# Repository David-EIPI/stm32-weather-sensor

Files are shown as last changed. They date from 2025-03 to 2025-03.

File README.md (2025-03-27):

# stm32-weather-sensor
Outdoor air sensor using STM32WB55 and Home Assistant Zigbee integration

## Overview
The primary goal of this project is to experiment with low-power modes of the STM32 microcontroller by building a Zigbee Sleepy End Device (SED) that can operate off-grid using solar power.

## Hardware
This project is based on the [WeAct STM32WB55-Core board](https://github.com/WeActStudio/WeActStudio.STM32WB55CoreBoard "Github link: STM32WB55 Core Board").  
This compact board provides essential features:
- LDO regulator: ME6231A33M3G, with 3–18 V input and 500 mA output.
- HSE oscillator: 32 MHz.
- LSE crystal: 32.678 kHz.
- Reverse-voltage protection MOSFET.
- GPIO-controlled blue LED (PE4).
- PCB antenna.

For sensing, I've considered either the BME280 or BMP280 paired with an AHT20. Both sensors are readily available on Aliexpress, pre-soldered onto breakout boards. The difference between these sensors is minimal, but in my tests, the BMP280+AHT20 pair provided slightly more accurate temperature and humidity measurements, thus making it into the final design.

In addition to the sensors, I've selected a small outdoor solar-powered light with a replaceable battery, also from Aliexpress. It acts both as the power source and enclosure while still serving its primary purpose as an outdoor light. There's sufficient space inside the enclosure to house the controller board. However, the sensor itself must be placed outside the casing, as the enclosure may heat up significantly in direct sunlight.

To monitor battery charge levels, I have implemented a simple voltage divider. While straightforward to implement, its downside is a continuous, albeit minimal, background battery discharge. To mitigate this, I used two high-value resistors (1MΩ and 330KΩ), minimizing the discharge current. Testing with the ADC revealed that about 50 ms of sampling is needed to measure battery voltage accurately. For the project's purpose, this sampling time is acceptable.

## Zigbee Setup
Since this sensor is battery-powered, it must be configured as a sleepy end device. The firmware implements one endpoint and four measurement clusters:

- Temperature
- Humidity
- Pressure
- Voltage

Battery voltage is reported through AC voltage attributes, as ZHA does not currently support DC voltage measurements.

Pairing the STM32WB55 with ZHA can be somewhat challenging. STM's implementation of SED involves aggressive power-saving optimizations. Upon joining a Zigbee network, the firmware immediately switches to low-power mode with default polling intervals of 30 seconds. ZHA, however, expects the device to report its configuration, clusters, attributes, and values. Due to the default SED polling interval, ZHA often times out, resulting in an incomplete device setup in Home Assistant.

A solution that I've found effective—though not consistently—is temporarily enabling a fast-polling mode for a few minutes immediately after joining the network for the first time.

Additionally, several other ZHA-specific adjustments are configured in the ZHA quirk file. The default reporting configuration is overly conservative and infrequent. I also prefer sensor readings with greater decimal precision.

The connection information is stored in persistent storage, enabling automatic re-joining to the network upon controller restart.

The device page in Home Assistant should appear as follows:  
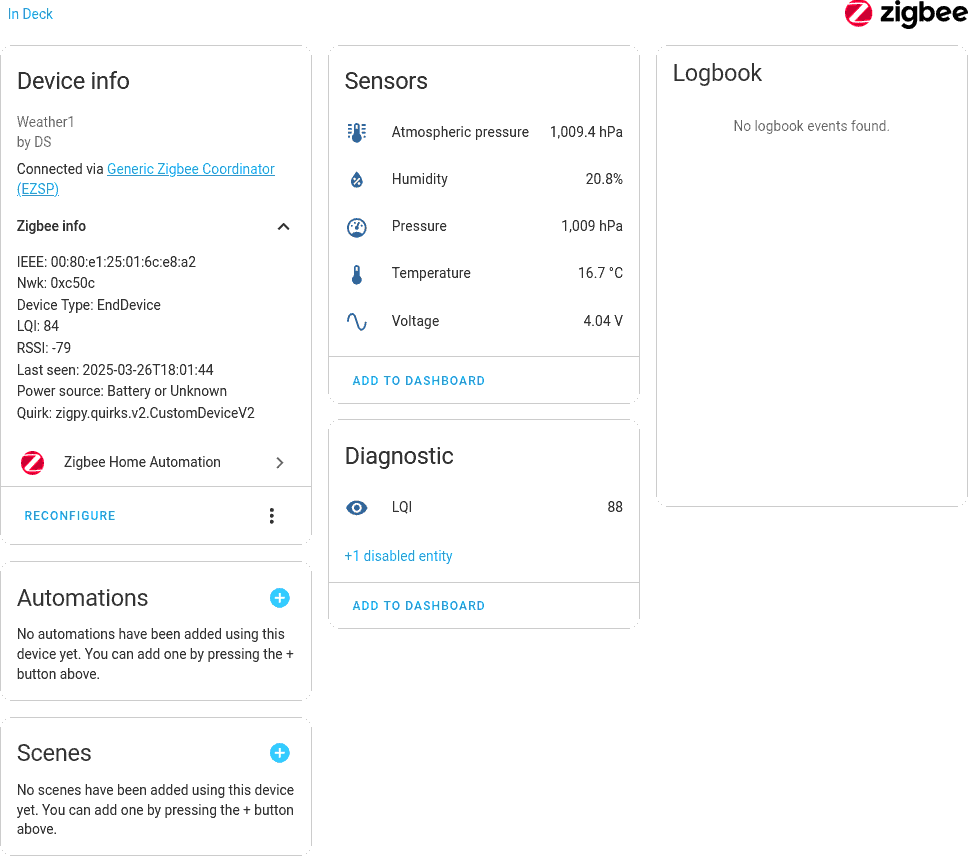
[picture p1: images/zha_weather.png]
Home Assistant device view


## Power Usage
The firmware is configured to wake up once every 20 seconds, perform sensor readings, and update the reportable attributes. The CPU spends the remainder of the time in STOP2 low-power mode. STOP2 is the deepest STOP mode and does not retain the I²C and ADC registers, requiring these peripherals to be re-initialized and shut down during each wake-up cycle.

Sensors are also powered down while the CPU is in the stopped state, thus requiring re-initialization upon wake-up.

The active phase lasts approximately 0.5 seconds and consumes about 5–15 mA for the entire system, including CPU, RF, and sensors. During the stopped phase, the CPU draws approximately 10 µA. Consequently, the average consumption is expected to be around 100–200 µA.

Without access to an integrating current meter, I resorted to a simple approach using an ultracapacitor to measure the average current consumption.

I charged a 30 F capacitor to 5.3 V and used it to power the sensor board. Voltage decay was recorded by the sensor itself, with Home Assistant capturing the data over time. After a few days, I obtained the voltage-versus-time plot shown below:  
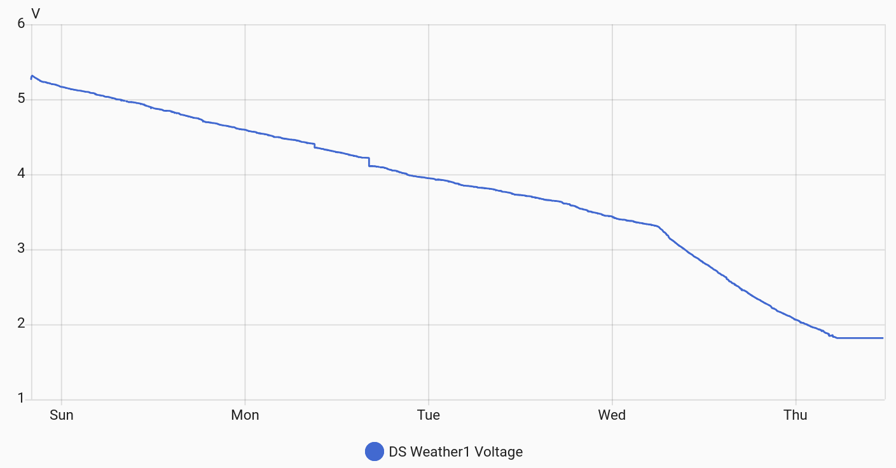
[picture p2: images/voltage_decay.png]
Capacitor voltage vs time


The voltage decay rate remains constant until reaching the LDO threshold of 3.3 V. At 1.8 V, the circuit shuts down completely. From the voltage decay slope, average current consumption can be estimated using:

I = C × dV/dt

The resulting calculation indicates approximately 200 µA of total current. Given that the ultracapacitor has a documented self-discharge rate of about 100 µA, the sensor itself consumes around 100 µA.

The documented battery capacity is 1200 mAh, thus a full day's operation of the sensor would minimally impact the battery's charge.

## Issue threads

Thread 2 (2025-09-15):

Join button

David-EIPI, 2025-09-15:
You are correct, most manufacturers add a button that initiates network discovery and joining. However, for my use case I did not expect frequent re-connections, so I have made it simple. On startup, my code attempts to join any network that is open for joining. Then my sensor will remain joined until the network coordinator requests it to leave.
It is fairly easy to implement a button if you need one. Just add a GPIO handler that sets some button press flag, and modify APP_ZIGBEE_NwkForm() to delay network formation until the button is pressed.

Closed 2025-09-22.

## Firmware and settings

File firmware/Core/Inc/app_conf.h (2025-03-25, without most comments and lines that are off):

#define APP_CONF_H
#include "hw.h"
#include "hw_conf.h"
#include "hw_if.h"
#define CFG_TL_EVT_QUEUE_LENGTH 5
#define CFG_TL_MOST_EVENT_PAYLOAD_SIZE 255
#define TL_EVENT_FRAME_SIZE ( TL_EVT_HDR_SIZE + CFG_TL_MOST_EVENT_PAYLOAD_SIZE )
#define CFG_DEBUG_TRACE_UART    hw_lpuart1
#define CFG_CONSOLE_MENU
#define CFG_CLI_UART            No UART selected
#define CFG_USB_INTERFACE_ENABLE    0
#define HAL_IPCC_TX_IRQHandler(...)  HW_IPCC_Tx_Handler( )
#define HAL_IPCC_RX_IRQHandler(...)  HW_IPCC_Rx_Handler( )
#define CFG_FULL_LOW_POWER    1
#if (CFG_FULL_LOW_POWER == 1)
#undef CFG_LPM_SUPPORTED
#define CFG_LPM_SUPPORTED   1
#endif
#define HAL_RTCEx_WakeUpTimerIRQHandler(...)  HW_TS_RTC_Wakeup_Handler( )
#define CFG_RTCCLK_DIVIDER_CONF 0
#if (CFG_RTCCLK_DIVIDER_CONF == 0)
#define CFG_RTCCLK_DIV            (16)
#define CFG_RTC_WUCKSEL_DIVIDER   (0)
#define CFG_RTC_ASYNCH_PRESCALER  (0x0F)
#define CFG_RTC_SYNCH_PRESCALER   (0x7FFF)
#else
#if (CFG_RTCCLK_DIVIDER_CONF == 2)
#define CFG_RTC_WUCKSEL_DIVIDER (3)
#endif
#if (CFG_RTCCLK_DIVIDER_CONF == 4)
#define CFG_RTC_WUCKSEL_DIVIDER (2)
#endif
#if (CFG_RTCCLK_DIVIDER_CONF == 8)
#define CFG_RTC_WUCKSEL_DIVIDER (1)
#endif
#if (CFG_RTCCLK_DIVIDER_CONF == 16)
#define CFG_RTC_WUCKSEL_DIVIDER (0)
#endif
#define CFG_RTCCLK_DIV              CFG_RTCCLK_DIVIDER_CONF
#define CFG_RTC_ASYNCH_PRESCALER    (CFG_RTCCLK_DIV - 1)
#define CFG_RTC_SYNCH_PRESCALER     (DIVR( LSE_VALUE, (CFG_RTC_ASYNCH_PRESCALER+1) ) - 1 )
#endif
#define CFG_TS_TICK_VAL           DIVR( (CFG_RTCCLK_DIV * 1000000), LSE_VALUE )
#define CFG_TS_TICK_VAL_PS        DIVR( ((uint64_t)CFG_RTCCLK_DIV * 1e12), (uint64_t)LSE_VALUE )
typedef enum
{
  CFG_TIM_PROC_ID_ISR,
  CFG_TIM_ZIGBEE_APP_BME280_REPEAT,
  CFG_TIM_ZIGBEE_STOP_FASTPOLL_ONESHOT,
} CFG_TimProcID_t;
#define CFG_HW_RESET_BY_FW         0
#define CFG_DEBUGGER_SUPPORTED    0
#if (CFG_FULL_LOW_POWER == 1)
#undef CFG_DEBUGGER_SUPPORTED
#define CFG_DEBUGGER_SUPPORTED    0
#endif
#define CFG_DEBUG_TRACE    0
#if (CFG_FULL_LOW_POWER == 1)
#undef CFG_DEBUG_TRACE
#define CFG_DEBUG_TRACE      0
#endif
#define CFG_DEBUG_TRACE_LIGHT     1
#define CFG_DEBUG_TRACE_FULL      1
#if (( CFG_DEBUG_TRACE != 0 ) && ( CFG_DEBUG_TRACE_LIGHT == 0 ) && (CFG_DEBUG_TRACE_FULL == 0))
#undef CFG_DEBUG_TRACE_FULL
#undef CFG_DEBUG_TRACE_LIGHT
#define CFG_DEBUG_TRACE_FULL      0
#define CFG_DEBUG_TRACE_LIGHT     1
#endif
#if ( CFG_DEBUG_TRACE == 0 )
#undef CFG_DEBUG_TRACE_FULL
#undef CFG_DEBUG_TRACE_LIGHT
#define CFG_DEBUG_TRACE_FULL      0
#define CFG_DEBUG_TRACE_LIGHT     0
#endif
#define DBG_TRACE_USE_CIRCULAR_QUEUE 1
#define DBG_TRACE_MSG_QUEUE_SIZE 4096
#define MAX_DBG_TRACE_MSG_SIZE   1024
#define APPLI_CONFIG_LOG_LEVEL    LOG_LEVEL_DEBG
#define APPLI_PRINT_FILE_FUNC_LINE    0
#define SENSOR_INTERVAL 20
#define USE_AHT20 1
#define MANUFACTURER_NAME "\x02" "DS"
#define MODEL_NAME "\x08" "Weather1"
#define LOCATION "\x0f" "Weather station"
#define DEFAULT_REPORT_MIN SENSOR_INTERVAL
#define DEFAULT_REPORT_MAX (DEFAULT_REPORT_MIN*60)
#define REPORT_KICK 0
#define USE_FASTPOLL 600
#define PERSIST_TIMEOUT 1000000
#define CFG_NB_OF_PAGE                          (16U)
#define CFG_EE_BANK0_SIZE                       (CFG_NB_OF_PAGE * HW_FLASH_PAGE_SIZE)
#define CFG_EE_BANK1_SIZE                       (CFG_NB_OF_PAGE * HW_FLASH_PAGE_SIZE)
#define CFG_NVM_BASE_ADDRESS                    ( 0x60000U )
#define CFG_EE_BANK0_MAX_NB                     (1000U)                  // In U32 words
#define CFG_EE_BANK1_MAX_NB                     (1000U)                  // In U32 words
#define ST_PERSIST_MAX_ALLOC_SZ                 (4U*CFG_EE_BANK0_MAX_NB) // Max data in bytes
#define ST_PERSIST_FLASH_DATA_OFFSET            (4U)
#define ZIGBEE_DB_START_ADDR                    (0U)
#define CFG_EE_AUTO_CLEAN                       (1U)
#define CFG_EE_TIMEOUT                          (10000U)                 // in milliseconds
#define CFG_USE_SMPS 1
typedef enum
{
  CFG_TASK_NOTIFY_FROM_M0_TO_M4,
  CFG_TASK_REQUEST_FROM_M0_TO_M4,
  CFG_TASK_ZIGBEE_NETWORK_FORM,
  CFG_TASK_SYSTEM_HCI_ASYNCH_EVT,
#if (CFG_USB_INTERFACE_ENABLE != 0)
  CFG_TASK_VCP_SEND_DATA,
#endif
  CFG_TASK_MAIN_LOOP,
  CFG_TASK_ZIGBEE_STOP_FASTPOLL,
  CFG_TASK_NBR
} CFG_IdleTask_Id_t;
#define EVENT_ACK_FROM_M0_EVT        (1U << CFG_EVT_ACK_FROM_M0_EVT)
#define EVENT_SYNCHRO_BYPASS_IDLE    (1U << CFG_EVT_SYNCHRO_BYPASS_IDLE)
typedef enum
{
  CFG_SCH_PRIO_0,
  CFG_SCH_PRIO_1,
  CFG_SCH_PRIO_NBR
} CFG_SCH_Prio_Id_t;
typedef enum
{
  CFG_EVT_SYSTEM_HCI_CMD_EVT_RESP,
  CFG_EVT_ACK_FROM_M0_EVT,
  CFG_EVT_SYNCHRO_BYPASS_IDLE,
  CFG_EVT_ZIGBEE_STARTUP_ENDED,
} CFG_IdleEvt_Id_t;
#define EVENT_ACK_FROM_M0_EVT           (1U << CFG_EVT_ACK_FROM_M0_EVT)
#define EVENT_SYNCHRO_BYPASS_IDLE       (1U << CFG_EVT_SYNCHRO_BYPASS_IDLE)
#define EVENT_ZIGBEE_STARTUP_ENDED      (1U << CFG_EVT_ZIGBEE_STARTUP_ENDED)
typedef enum
{
  CFG_LPM_APP,
  CFG_LPM_SENSORS,
  CFG_LPM_FASTPOLL,
} CFG_LPM_Id_t;
#define CFG_OTP_BASE_ADDRESS    OTP_AREA_BASE
#define CFG_OTP_END_ADRESS      OTP_AREA_END_ADDR

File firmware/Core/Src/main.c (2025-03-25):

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
/* Includes ------------------------------------------------------------------*/
#include "main.h"

/* USER CODE BEGIN Includes */
#include "stm32_seq.h"
#include "stm_logging.h"
#include "dbg_trace.h"
#include "zigbee.h"
#include "app_zigbee.h"
#include "stm32_lpm.h"
#include "stm32_lpm_if.h"
#include "hw_if.h"

#include "zcl/general/zcl.press.meas.h"
#include "zcl/general/zcl.temp.meas.h"
#include "zcl/general/zcl.elec.meas.h"
#include "zcl/general/zcl.wcm.h"

#include "bme280_support.h"
#include "aht20.h"
/* USER CODE END Includes */

/* USER CODE BEGIN PD */


#define HW_TS_SERVER_20S_NB_TICKS                    (SENSOR_INTERVAL *1000*1000/CFG_TS_TICK_VAL) /* 20s */
/* USER CODE END PD */


I2C_HandleTypeDef hi2c1;

IPCC_HandleTypeDef hipcc;

IWDG_HandleTypeDef hiwdg;

UART_HandleTypeDef hlpuart1;

RTC_HandleTypeDef hrtc;

/* USER CODE BEGIN PV */
struct bme280_data bme280_meas_data;

#if USE_AHT20

static aht20_data_t aht20_data;

#endif

uint8_t hwSensorTimerId = CFG_HW_TS_MAX_NBR_CONCURRENT_TIMER;
uint8_t hwActiveTimerId = CFG_HW_TS_MAX_NBR_CONCURRENT_TIMER;

static unsigned SysTicks_us = 0;

uint8_t adc_num_conversions = 0;
int vrefplus = 0;
int internal_tc = 0;
int adc1_voltage = 0;

unsigned iwdg_update_req = 0;
unsigned iwdg_update_cnt = 0;

/* USER CODE END PV */

void SystemClock_Config(void);
void PeriphCommonClock_Config(void);
static void MX_GPIO_Init(void);
static void MX_IPCC_Init(void);
static void MX_RTC_Init(void);
static void MX_I2C1_Init(void);
static void MX_IWDG_Init(void);
static void MX_ADC1_Init(void);
static void MX_LPTIM1_Init(void);
static void MX_LPUART1_UART_Init(void);
static void MX_RF_Init(void);
/* USER CODE BEGIN PFP */
static void setup_lptimer(void);

static void ADC_check(int idx);
static void ADC_check_print(void);

/* USER CODE END PFP */

/* USER CODE BEGIN 0 */

static uint32_t dbg_counter = 0, dbg_prev = 0;

static int wait_for_flag(uint32_t (*flag_func)(const ADC_TypeDef *ADCx), uint32_t flag)
{
	uint32_t timeout = 1000; //ms
	uint32_t count = 0;
	uint32_t prev = HAL_GetTick();

	while (flag_func(ADC1) != flag)
	{
		HAL_Delay(20);
		count = HAL_GetTick() - prev;
		if (count > timeout) {
			dbg_counter = count;
			dbg_prev = prev;
			return -1;
		}
	}
	return count;
}

static void read_voltage_and_temp(void)
{
	int32_t adc_readings[adc_num_conversions];
	int32_t wait_time[adc_num_conversions];

	if (LL_ADC_IsActiveFlag_ADRDY(ADC1) == 0) { /* ADC is not ready */
		APP_DBG("ADC not ready.");
		return;
	}

	unsigned i;
	for (i = 0; i < adc_num_conversions; i++) {
		LL_ADC_REG_StartConversion(ADC1);
		wait_time[i] = wait_for_flag(LL_ADC_IsActiveFlag_EOC, 1);
		if (wait_time[i] < 0) {
			APP_DBG("ADC CH%d timeout", i);
			return;
		}
		adc_readings[i] = LL_ADC_REG_ReadConversionData12(ADC1);
	}

	int vref_adc = adc_readings[0];
	int temp_adc = adc_readings[1];
	int ch1_adc  = adc_readings[2];

	if (vref_adc > 0)
		vrefplus = __LL_ADC_CALC_VREFANALOG_VOLTAGE(vref_adc, LL_ADC_RESOLUTION_12B);
	if(temp_adc > 0)
		internal_tc = 100* __LL_ADC_CALC_TEMPERATURE(vrefplus, temp_adc, LL_ADC_RESOLUTION_12B);

	adc1_voltage = __LL_ADC_CALC_DATA_TO_VOLTAGE(vrefplus, ch1_adc, LL_ADC_RESOLUTION_12B);
}

/* Enable the ADC as explained in Examples_LL/ADC_SingleConversion_TriggerSW_Init */
static int adc_enable(void)
{
	/* First, turn on the power */
	LL_ADC_DisableDeepPowerDown(ADC1);
	LL_ADC_EnableInternalRegulator(ADC1);

	/* Delay for voltage regulator stabilization */
	HAL_Delay(1);

	/* Clear ADC group regular conversion flag and overrun flag               */
    /* (To ensure of no unknown state from potential previous ADC operations) */
	LL_ADC_ClearFlag_EOC(ADC1);
	LL_ADC_ClearFlag_EOS(ADC1);
	LL_ADC_ClearFlag_EOSMP(ADC1);
	LL_ADC_ClearFlag_OVR(ADC1);

	/* Run ADC self calibration and wait for completion */
    LL_ADC_StartCalibration(ADC1, LL_ADC_SINGLE_ENDED);
    if (wait_for_flag(LL_ADC_IsCalibrationOnGoing, 0) < 0) {
    	ADC_check(1);
    	return -1;
    }
	/* Another short delay is needed here */
	HAL_Delay(1);

	/* Now enable the ADC and wait for its Ready flag */
	LL_ADC_Enable(ADC1);
	if (wait_for_flag(LL_ADC_IsActiveFlag_ADRDY, 1) < 0) {
		return -2;
	}
//	APP_DBG("ADC regs: CR:0x%x ISR:0x%x", ADC1->CR, ADC1->ISR);
	return 0;
}

/* Disable the ADC as described in RM034*/
static void adc_disable(void)
{
	/* Stop conversions and wait for ADSTP to clear*/
	LL_ADC_REG_StopConversion(ADC1);
	while (LL_ADC_REG_IsStopConversionOngoing(ADC1)) {}

	/* Clear Ready flag */
	LL_ADC_ClearFlag_ADRDY(ADC1);

	/* Set disable bit and wait for ADEN to clear */
	LL_ADC_Disable(ADC1);
	while (LL_ADC_IsEnabled(ADC1)) {}

	/* Finally, cut the power */
	LL_ADC_DisableInternalRegulator(ADC1);
	LL_ADC_EnableDeepPowerDown(ADC1);
}


/*
 * Main application loop. Read the sensors and update Zigbee attributes.
 * */

void seq_main_loop(void)
{
	LL_GPIO_SetOutputPin(BME280_Supply_GPIO_Port, BME280_Supply_Pin);

	HAL_Delay(10);

	MX_I2C1_Init();

	int adc_res = adc_enable();
	if (0 == adc_res) {
		read_voltage_and_temp();
		if (0 == adc1_voltage) {
			APP_DBG("ADC regs: CR:0x%x ISR:0x%x", ADC1->CR, ADC1->ISR);
		}
	} else {
		APP_DBG("ADC error: %d", adc_res);
		ADC_check_print();
		APP_DBG("Timeout counters: %u, %u", dbg_counter, dbg_prev);
	}

	adc_disable();

	/*
	 * Voltage at the ADC pin is produced by the voltage divider, where R1=1M, and R2=330K.
	 * After calibration I have obtained this ratio: 8105/2048, choosing power of 2 as a scale for performance reason.
	 * */
	int vdd_divided = (adc1_voltage * 8105) / 2048;

	/* Update the ADC attributes so that C2 can possibly begin transmission while we read the I2C sensors. */
	APP_ZIGBEE_update_ADC_outputs(vdd_divided);

	int8_t bme280_status = bme280_setup();

#if USE_AHT20
	HAL_Delay(50);
	aht_status_t aht_status = aht20_setup();
#endif

	if (BME280_OK == bme280_status) {
		bme280_status = bme280_read_measurements(&bme280_meas_data);
		bme280_meas_data.humidity = (bme280_meas_data.humidity * 100 + 512) / 1024;
	}

	if (BME280_OK != bme280_status) {
		bme280_meas_data.temperature = ZCL_TEMP_MEAS_UNKNOWN;
		bme280_meas_data.pressure = ZCL_PRESS_MEAS_UNKNOWN;
		bme280_meas_data.humidity = ZCL_WC_MEAS_UNKNOWN;

	}

#if USE_AHT20
	bme280_meas_data.humidity = ZCL_WC_MEAS_UNKNOWN;
	if (AHT_NO_ERROR == aht_status) {
		HAL_Delay(50);
		aht_status = aht20_read_measurements(&aht20_data);
		if (AHT_NO_ERROR == aht_status) {
			bme280_meas_data.humidity = aht20_data.humidity;
		}

		/* Use AHT temperature measurement if BMP280 data is unavailable. */
		if (ZCL_TEMP_MEAS_UNKNOWN == bme280_meas_data.temperature) {
			bme280_meas_data.temperature = aht20_data.temperature;
		}
	}
#endif

	LL_GPIO_ResetOutputPin(BME280_Supply_GPIO_Port, BME280_Supply_Pin);
	HAL_I2C_DeInit(&hi2c1);

	/* Update the attributes with fresh data*/
	APP_ZIGBEE_update_BME280_outputs(bme280_meas_data.temperature,
		bme280_meas_data.pressure, bme280_meas_data.humidity);

}


static void rtc_read_update_sensors(void)
{
	/* Queue the sensor readout routine to be run in the main application loop. */
	UTIL_SEQ_SetTask(1<< CFG_TASK_MAIN_LOOP, CFG_SCH_PRIO_0);

	/* Check Zigbee link health and request IWDG refresh if appropriate. */
	zigbee_check_link();

	if (iwdg_update_req != iwdg_update_cnt) {
	    iwdg_update_cnt = iwdg_update_req;
	    HAL_IWDG_Refresh(&hiwdg);
	    APP_DBG("Watchdog refreshed.")
	}
}
void startSensorUpdates(void)
{
	if (hwSensorTimerId != CFG_HW_TS_MAX_NBR_CONCURRENT_TIMER) {
//		UTIL_SEQ_SetTask(1<< CFG_TASK_MAIN_LOOP, CFG_SCH_PRIO_0);
		seq_main_loop();
		HW_TS_Start(hwSensorTimerId, HW_TS_SERVER_20S_NB_TICKS);
	}
}

void stopSensorUpdates(void)
{
	if (hwSensorTimerId != CFG_HW_TS_MAX_NBR_CONCURRENT_TIMER) {
		HW_TS_Stop(hwSensorTimerId);
	}
}

/* Setup daily restart */
void HAL_RTC_AlarmAEventCallback(RTC_HandleTypeDef *hrtc)
{
	HAL_NVIC_SystemReset();
}

#if CFG_DEBUG_TRACE
/* Debugging routine to direct the log output to the USB */
int _write(int file, char *ptr, int len) {

	HAL_StatusTypeDef res = HAL_UART_Transmit(&hlpuart1, (uint8_t *)ptr, len, 2000);
	if (HAL_OK != res)
		return 0;
	return len;
}
#endif

/*
 * Set the flag allowing to refresh IWDG in the next RTC timer call, see rtc_read_update_sensors().
 */
void update_watchdog(void)
{
  iwdg_update_req += 1;
}
/* USER CODE END 0 */

/**
  * @brief  The application entry point.
  * @retval int
  */
int main(void)
{

  /* USER CODE BEGIN 1 */
/*
 * Disable auto-generated initialization calls
 */
#define MX_I2C1_Init()

#if  !CFG_DEBUG_TRACE
#define MX_LPUART1_UART_Init()
#endif
  /* USER CODE END 1 */

  /* MCU Configuration--------------------------------------------------------*/

  /* Reset of all peripherals, Initializes the Flash interface and the Systick. */
  HAL_Init();
  /* Config code for STM32_WPAN (HSE Tuning must be done before system clock configuration) */
  MX_APPE_Config();

  /* Configure the system clock */
  SystemClock_Config();

/* Configure the peripherals common clocks */
  PeriphCommonClock_Config();

  /* IPCC initialisation */
  MX_IPCC_Init();

  /* USER CODE BEGIN SysInit */
  SysTicks_us = SystemCoreClock / 1000000U;
  /* USER CODE END SysInit */

  /* Initialize all configured peripherals */
  MX_GPIO_Init();
  MX_RTC_Init();
  MX_I2C1_Init();
  MX_IWDG_Init();
  MX_ADC1_Init();
  MX_LPTIM1_Init();
  MX_LPUART1_UART_Init();
  MX_RF_Init();
  /* USER CODE BEGIN 2 */
  ADC_check_print();

#undef MX_I2C1_Init

#if  !CFG_DEBUG_TRACE
#undef MX_LPUART1_UART_Init
#endif
  /* USER CODE END 2 */

  /* Init code for STM32_WPAN */
  MX_APPE_Init();

  /* Infinite loop */
  /* USER CODE BEGIN WHILE */
  UTIL_SEQ_RegTask(1U << CFG_TASK_MAIN_LOOP, UTIL_SEQ_RFU, seq_main_loop);

  if (hw_ts_Successful != HW_TS_Create(CFG_TIM_ZIGBEE_APP_BME280_REPEAT, &hwSensorTimerId, hw_ts_Repeated, rtc_read_update_sensors)) {
	  hwSensorTimerId = CFG_HW_TS_MAX_NBR_CONCURRENT_TIMER;
  }
/*
  if (hw_ts_Successful != HW_TS_Create(CFG_TIM_ZIGBEE_APP_BME280_ONESHOT, &hwActiveTimerId, hw_ts_SingleShot, enable_power_saving_mode)) {
	  hwActiveTimerId = CFG_HW_TS_MAX_NBR_CONCURRENT_TIMER;
  }
*/
  while (1)
  {
    /* USER CODE END WHILE */
    MX_APPE_Process();

    /* USER CODE BEGIN 3 */
  }
  /* USER CODE END 3 */
}

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
/* USER CODE BEGIN 4 */
#if CFG_DEBUG_TRACE
struct adc_config_params {
	const char *desc;
	uint32_t values[2];
} adc_config_params[] = {
	{ .desc = "Clock source :", },
	{ .desc = "Clock enabled:", },
	{ .desc = "PLL Config   :", },
	{ .desc = "PLLSAI1 MulN :", },
	{ .desc = "PLLSAI1 DivP :", },
	{ .desc = "ADC Freq     :", },
	{ .desc = "Pin mode     :", },
	{ .desc = "Common clock :", },
	{ .desc = "Low power    :", },
	{ .desc = "SW Trigger   :", },
	{ .desc = "Power down   :", },
	{ .desc = "Int Regulator:", },
	{ .desc = "Int Channels :", },
	{ .desc = "CR reg       :", },
	{ .desc = "ISR reg      :", },
	{ .desc = "Rank 1 Chan  :", },
	{ .desc = "Rank 1 Time  :", },
	{ .desc = "Rank 1 Diff  :", },
	{ .desc = "Rank 2 Chan  :", },
	{ .desc = "Rank 2 Time  :", },
	{ .desc = "Rank 2 Diff  :", },
	{ .desc = "Rank 3 Chan  :", },
	{ .desc = "Rank 3 Time  :", },
	{ .desc = "Rank 3 Diff  :", },
};
#endif

static void ADC_check(int idx)
{
#if CFG_DEBUG_TRACE
	int q, p = 0;
	adc_config_params[p++].values[idx] = LL_RCC_GetADCClockSource(LL_RCC_ADC_CLKSOURCE);
	adc_config_params[p++].values[idx] = LL_AHB2_GRP1_IsEnabledClock(LL_AHB2_GRP1_PERIPH_ADC);
	adc_config_params[p++].values[idx] = __HAL_RCC_GET_PLLCLKOUT_CONFIG(RCC_PLL_SAI1CLK);
	adc_config_params[p++].values[idx] = LL_RCC_PLLSAI1_GetN();
	adc_config_params[p++].values[idx] = LL_RCC_PLLSAI1_GetP();
	adc_config_params[p++].values[idx] = LL_RCC_GetADCClockFreq(LL_RCC_ADC_CLKSOURCE);
	adc_config_params[p++].values[idx] = LL_GPIO_GetPinMode(GPIOA, LL_GPIO_PIN_2);
	adc_config_params[p++].values[idx] = LL_ADC_GetCommonClock(__LL_ADC_COMMON_INSTANCE(ADC1));
	adc_config_params[p++].values[idx] = LL_ADC_GetLowPowerMode(ADC1);
	adc_config_params[p++].values[idx] = LL_ADC_REG_IsTriggerSourceSWStart(ADC1);
	adc_config_params[p++].values[idx] = LL_ADC_IsDeepPowerDownEnabled(ADC1);
	adc_config_params[p++].values[idx] = LL_ADC_IsInternalRegulatorEnabled(ADC1);
	adc_config_params[p++].values[idx] = LL_ADC_GetCommonPathInternalCh(__LL_ADC_COMMON_INSTANCE(ADC1));
	adc_config_params[p++].values[idx] = ADC1->CR;
	adc_config_params[p++].values[idx] = ADC1->ISR;
	adc_config_params[p++].values[idx] = LL_ADC_REG_GetSequencerRanks(ADC1, LL_ADC_REG_RANK_1);
	q = p;
	adc_config_params[p++].values[idx] = LL_ADC_GetChannelSamplingTime(ADC1, adc_config_params[q].values[idx]);
	adc_config_params[p++].values[idx] = LL_ADC_GetChannelSingleDiff(ADC1, adc_config_params[q].values[idx]);
	adc_config_params[p++].values[idx] = LL_ADC_REG_GetSequencerRanks(ADC1, LL_ADC_REG_RANK_2);
	q = p;
	adc_config_params[p++].values[idx] = LL_ADC_GetChannelSamplingTime(ADC1, adc_config_params[q].values[idx]);
	adc_config_params[p++].values[idx] = LL_ADC_GetChannelSingleDiff(ADC1, adc_config_params[q].values[idx]);
	adc_config_params[p++].values[idx] = LL_ADC_REG_GetSequencerRanks(ADC1, LL_ADC_REG_RANK_3);
	q = p;
	adc_config_params[p++].values[idx] = LL_ADC_GetChannelSamplingTime(ADC1, adc_config_params[q].values[idx]);
	adc_config_params[p++].values[idx] = LL_ADC_GetChannelSingleDiff(ADC1, adc_config_params[q].values[idx]);
#endif
}

static void ADC_check_print(void)
{
#if CFG_DEBUG_TRACE
	unsigned n = sizeof(adc_config_params) / sizeof(adc_config_params[0]);
	unsigned n2 = n / 2;
	unsigned i;
	for (i = 0; i < n - n2; i++) {
		unsigned i2 = i + n - n2;
		if (i2 < n) {
			APP_DBG("%s %08x %08x\t%s %08x %08x",
					adc_config_params[i].desc, adc_config_params[i].values[0], adc_config_params[i].values[1],
					adc_config_params[i2].desc, adc_config_params[i2].values[0], adc_config_params[i2].values[1])
		} else {
			APP_DBG("%s %08x %08x", adc_config_params[i].desc, adc_config_params[i].values[0], adc_config_params[i].values[1])
		}
	}
#endif
}

#if defined (LPTIM1)
static uint32_t lp_tick = 0;
static uint16_t lp_prev_counter = 0;

/*
 * Count ticks in Run or Stop modes.
 * LPTIM1 is set with 1/32 divider so that it counts milliseconds.
 * To prevent the counter overflow this GetTick function needs to be called
 * at least once every 65.535 seconds.
 * */
uint32_t HAL_GetTick(void)
{
	if (0 == LPTIM1->ARR) {
		lp_tick = uwTick;
	} else {
		uint16_t counter = LL_LPTIM_GetCounter(LPTIM1);
		uint16_t delta = counter - lp_prev_counter;
		lp_tick += (uint32_t)delta;
		lp_prev_counter += delta;
	}
	return lp_tick;
}

HAL_StatusTypeDef HAL_InitTick(uint32_t TickPriority)
{
	SysTick_Config(HAL_RCC_GetHCLKFreq() / 1000U);
	uwTickFreq = 1;

	if (0 != LPTIM1->ARR) { /* Timer has already been initialized */
		LL_LPTIM_Enable(LPTIM1);
		while (!LL_LPTIM_IsEnabled(LPTIM1)) { ; }
		LL_LPTIM_StartCounter(LPTIM1, LL_LPTIM_OPERATING_MODE_CONTINUOUS);
	} else {
		lp_tick = 0;
	}
	HAL_StatusTypeDef  status = HAL_OK;
	return status;
}

static void setup_lptimer(void)
{
	LL_LPTIM_Enable(LPTIM1);
	while (!LL_LPTIM_IsEnabled(LPTIM1)) { ; }
	LL_LPTIM_SetAutoReload(LPTIM1, ~0);
	LL_LPTIM_StartCounter(LPTIM1, LL_LPTIM_OPERATING_MODE_CONTINUOUS);
}
#endif

/* USER CODE END 4 */
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


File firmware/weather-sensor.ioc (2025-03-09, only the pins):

Mcu.UserName=STM32WB55CGUx
PA0.GPIO_Label=BME280_Supply
PA0.Signal=GPIO_Output
PA2.Signal=ADCx_IN7
PA3.Signal=LPUART1_RX
PB5.Signal=LPUART1_TX
PB8.Signal=I2C1_SCL
PB9.Signal=I2C1_SDA
PC14-OSC32_IN.Signal=RCC_OSC32_IN
PC15-OSC32_OUT.Signal=RCC_OSC32_OUT
PE4.GPIO_Label=BOARDLED
PE4.Signal=GPIO_Output

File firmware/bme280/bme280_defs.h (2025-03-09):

/**
* Copyright (c) 2020 Bosch Sensortec GmbH. All rights reserved.
*
* BSD-3-Clause
*
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
* 1. Redistributions of source code must retain the above copyright
*    notice, this list of conditions and the following disclaimer.
*
* 2. Redistributions in binary form must reproduce the above copyright
*    notice, this list of conditions and the following disclaimer in the
*    documentation and/or other materials provided with the distribution.
*
* 3. Neither the name of the copyright holder nor the names of its
*    contributors may be used to endorse or promote products derived from
*    this software without specific prior written permission.
*
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
* @file       bme280_defs.h
* @date       2020-12-17
* @version    v3.5.1
*
*/

#ifndef _BME280_DEFS_H
#define _BME280_DEFS_H

/********************************************************/
/* header includes */
#ifdef __KERNEL__
#include <linux/types.h>
#include <linux/kernel.h>
#else
#include <stdint.h>
#include <stddef.h>
#endif

/********************************************************/
/*! @name       Common macros               */
/********************************************************/

#if !defined(UINT8_C) && !defined(INT8_C)
#define INT8_C(x)    S8_C(x)
#define UINT8_C(x)   U8_C(x)
#endif

#if !defined(UINT16_C) && !defined(INT16_C)
#define INT16_C(x)   S16_C(x)
#define UINT16_C(x)  U16_C(x)
#endif

#if !defined(INT32_C) && !defined(UINT32_C)
#define INT32_C(x)   S32_C(x)
#define UINT32_C(x)  U32_C(x)
#endif

#if !defined(INT64_C) && !defined(UINT64_C)
#define INT64_C(x)   S64_C(x)
#define UINT64_C(x)  U64_C(x)
#endif

/**@}*/
/**\name C standard macros */
#ifndef NULL
#ifdef __cplusplus
#define NULL         0
#else
#define NULL         ((void *) 0)
#endif
#endif

/******************************************************************************/
/*! @name        Compiler switch macros Definitions                */
/******************************************************************************/
#ifndef BME280_64BIT_ENABLE /*< Check if 64-bit integer (using BME280_64BIT_ENABLE) is enabled */
#ifndef BME280_32BIT_ENABLE /*< Check if 32-bit integer (using BME280_32BIT_ENABLE) is enabled */
#ifndef BME280_DOUBLE_ENABLE /*< If any of the integer data types not enabled then enable BME280_DOUBLE_ENABLE */
#define BME280_DOUBLE_ENABLE
#endif
#endif
#endif

/******************************************************************************/
/*! @name        General Macro Definitions                */
/******************************************************************************/
#ifndef TRUE
#define TRUE                                      UINT8_C(1)
#endif
#ifndef FALSE
#define FALSE                                     UINT8_C(0)
#endif

/*!
 * BME280_INTF_RET_TYPE is the read/write interface return type which can be overwritten by the build system.
 */
#ifndef BME280_INTF_RET_TYPE
#define BME280_INTF_RET_TYPE                      int8_t
#endif

/*!
 * The last error code from read/write interface is stored in the device structure as intf_rslt.
 */
#ifndef BME280_INTF_RET_SUCCESS
#define BME280_INTF_RET_SUCCESS                   INT8_C(0)
#endif

/*! @name API success code */
#define BME280_OK                                 INT8_C(0)

/*! @name API error codes */
#define BME280_E_NULL_PTR                         INT8_C(-1)
#define BME280_E_COMM_FAIL                        INT8_C(-2)
#define BME280_E_INVALID_LEN                      INT8_C(-3)
#define BME280_E_DEV_NOT_FOUND                    INT8_C(-4)
#define BME280_E_SLEEP_MODE_FAIL                  INT8_C(-5)
#define BME280_E_NVM_COPY_FAILED                  INT8_C(-6)

/*! @name API warning codes */
#define BME280_W_INVALID_OSR_MACRO                INT8_C(1)

/*! @name BME280 chip identifier */
#define BME280_CHIP_ID                            UINT8_C(0x60)

/*! @name BMP280 chip identifier */
#define BMP280_CHIP_ID                            UINT8_C(0x58)

/*! @name I2C addresses */
#define BME280_I2C_ADDR_PRIM                      UINT8_C(0x76)
#define BME280_I2C_ADDR_SEC                       UINT8_C(0x77)

/*! @name Register Address */
#define BME280_REG_CHIP_ID                        UINT8_C(0xD0)
#define BME280_REG_RESET                          UINT8_C(0xE0)
#define BME280_REG_TEMP_PRESS_CALIB_DATA          UINT8_C(0x88)
#define BME280_REG_HUMIDITY_CALIB_DATA            UINT8_C(0xE1)
#define BME280_REG_CTRL_HUM                       UINT8_C(0xF2)
#define BME280_REG_STATUS                         UINT8_C(0xF3)
#define BME280_REG_PWR_CTRL                       UINT8_C(0xF4)
#define BME280_REG_CTRL_MEAS                      UINT8_C(0xF4)
#define BME280_REG_CONFIG                         UINT8_C(0xF5)
#define BME280_REG_DATA                           UINT8_C(0xF7)

/*! @name Macros related to size */
#define BME280_LEN_TEMP_PRESS_CALIB_DATA          UINT8_C(26)
#define BME280_LEN_HUMIDITY_CALIB_DATA            UINT8_C(7)
#define BME280_LEN_P_T_H_DATA                     UINT8_C(8)
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

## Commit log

2025-03-09 Bring back some code removed due to a bug in STM32. Also, move EE driver out of the IDE-maintained tree to add timeout code.
    [app_conf.h, app_zigbee.c, ee.c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]
2025-03-25 Tweak Zigbee endpoint configuration. Tweak EEPROM emulation parameters. Restore LPTIM1 use for ms delays. Replace watchdog update variable by a function = better code style.
    [app_conf.h, app_zigbee.c, ee.c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]
2025-03-25 Add schematics, quirk and illustration plot image.
    [weather_sensor.kicad_sch]
2025-07-11 Add more photos of the sensor and its wiring.
2026-02-25 * Switch voltage measurement cluster from AC to DC since HA now supports DC measurements.
    * Fix data type for temperature cluster to signed int to allow negative
    C temperatures.
    * Disable sleeping mode when solar panel charges battery above 4.2V limit
    to drain some energy and prevent overcharging.

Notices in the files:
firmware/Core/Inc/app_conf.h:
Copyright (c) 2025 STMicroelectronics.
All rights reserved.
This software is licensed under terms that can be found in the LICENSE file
